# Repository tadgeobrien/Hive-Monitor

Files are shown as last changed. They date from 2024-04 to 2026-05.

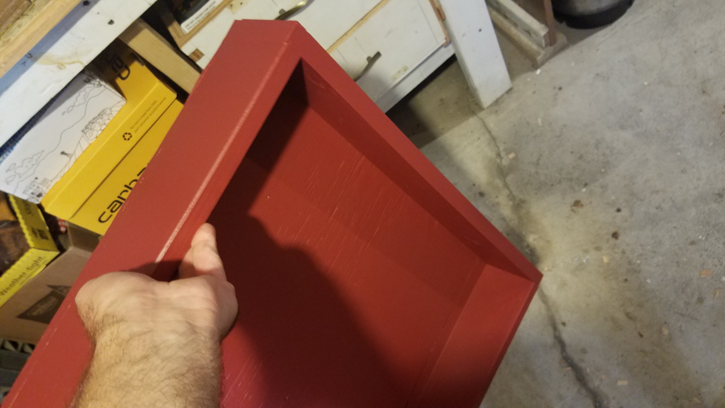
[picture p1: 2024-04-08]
ProgressPics/20220801_100242.jpg

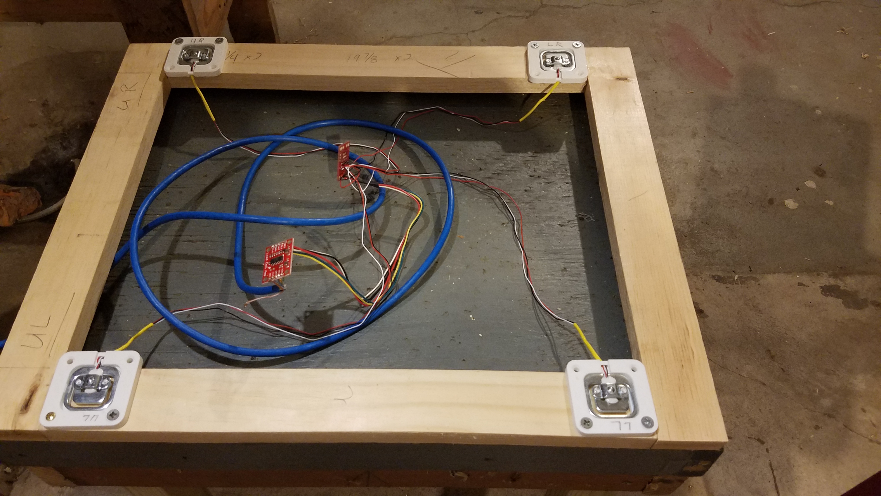
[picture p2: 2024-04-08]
ProgressPics/20220707_214736.jpg

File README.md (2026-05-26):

# Development Log

#20260525 

CURRENT WORKING FILE HiveMonitor-20260525-01/HiveMonitor-20260525-01.ino

I am going to redo this. I am going to focus on just getting things into openlog first. I am going to start with the temperatures and then add the scale.

- [X] Outside temperature working Serial Out. Need to verify inside OpenLog.
- [X] Inside Temp should be working now too.

Was messing with the zeroing and this is the number I was getting back. Not sure if it is correct. But Just using as a reference at this point.
Remove all weight from the loadcell
15:21:51.644 -> and press enter
15:21:51.644 -> 
15:22:13.270 -> Determine zero weight offset
15:22:14.995 -> OFFSET: 8388607
15:22:14.995 -> 
15:22:14.995 -> place a weight on the loadcell
15:22:14.995 -> enter the weight in (whole) grams and press enter
15:22:45.779 -> WEIGHT: 1134
15:22:47.438 -> SCALE:  0.000000
15:22:47.438 -> 
15:22:47.438 -> use scale.set_offset(8388607); and scale.set_scale(0.000000);
15:22:47.438 -> in the setup of your project

## 20250703 @ 18:02 - 
  TOBrien made a copy of the old hive monitor from 2024 and tried to get the weight to print. Currenlty not getting weight to print, but also appears that the one wire (external temp) is broken as I am seeing 
  -127 as a value. It was working before, but I have no idea what code I was actually running. I think I am going to make a text weight set of code and see if I can get that working with out anything else. 
  
  Currenlty working on the weight. Appears to be holding a decent "lbs" related to what I think I should get. 
  Next set of steps. 
  
- [X] I think I should get a hive body and mout it to the physical box that I have and apply wire the basic electronics. Teflon tap around humidity sensor and 1/8" wire mesh around the hole. 
- [X] Need an outdoor electronics box to put underneath to hold the scale components.
- [ ] Then I should look at how I am going to secure and waterproof the stuff that I have. Most likely silicoln over wires and connections. 
- [ ] Then start to look at how are you going to address the solar component of this. 
- [ ] Clear silicoln to cover any electronics that might be exposed (wiring mostly) 
- [ ] Define sample rate. I think that every 30 minutes would be sufficent. It would give you a sense of material coming in and going out I would think.

# Hive Montitor

NOTE--- I used the Sparkfun Qwiic shield which was originaly designed for the Uno. However the Uno Wifi Rev2 that I have has two pins that are different. 
        So to solve this the following has to be done. (https://forum.sparkfun.com/viewtopic.php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)
        
        The pins not going in all the way is normal, it's caused by the USB connector being higher than normal.
        We haven't tested the Qwiic Shield on the Uno WiFi V2 but it should work with this small change:
            Connect a jumper wire from A5 to SCL
            Connect a jumper wire from A4 to SDA

        The reason for the jumper wires is that the shield was made for the regular non WiFi Uno where the I2C pins are on A4 and A5 and the Uno WiFi V2 moves those pins over to the other side of the board. With the jumpers in place, the shield will work even though it doesn't sit flush with the Arduino. 

Of course now they have the Uno R4 Wifi which has a Qwiic connector built in GRRRR https://store-usa.arduino.cc/products/uno-r4-wifi .

## Winterizing
Not sure how the batteries would hold up in the winter. Would really need to look at this as I don't want to start a fire. 

## Goal

Create a simple set of sensors to monitor a beehive of mine. It will be solar powered and not connected to any network. 
The sensors that I will be using are as follows:
* Weight Measure
* Inside Temperature and Humidity Measure
* Outside Temperature Measure
* Leverage Meshtastic service to send a daily update via LoRa

## To Dos
- [ ] Should do something so I can zero the scale. Use the wifi control to do this?
- [ ] Do I need a way to update the current data on the webpage from the webpage without adding to the Openlog file?
- [ ] Implement battery power reading on webpage and openlog?
- [ ] Implement solar power 
- [ ] Implement way to download Data from web pagea
- [ ] Set up low power mode on anything that can do it. Ie WiFi.lowPowerMode() for the wifi.
- [X] Have RTC implemented on website TOBRIEN 20251229 I think that this is working right now.
- [X] Implement Weight measures (may leave with weight errors currently.) https://learn.sparkfun.com/tutorials/load-cell-amplifier-hx711-breakout-hookup-guide/all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 https://github.com/bogde/HX711/
- [X] Have Openlog recieving all current values of data
- [X] Have Openlog implemented and getting data
- [X] Have RTC working
- [X] Have Inside temp and humidity report on website
- [X] Have Inside humidity working
- [X] Have Inside temp working 
- [X] Have Outside temp appear on webpage.
- [X] Set up Onewire for outside temperature 
- [X] Set up an Webserver and wireless connection to the Arduino. 

## CSV Structure

CSV Structure should look like this. 
(24 entries per day and role log monthly would give at most 744 points of data.)
Could scale up if needed in the future.

Not sure if the date will go as I want, but I should try. Also not sure exactly if I would want it like
this or break it out Year,Month,Day,Hour,Minute,

DATE,TIME-24:00,% Humidity,InternalTemp(C),OutsideTemp(C),Weight(lbs)
20240420,00:20,24,31,1,95
20240420,01:20,24,31,1,95
20240420,02:20,24,31,1,95
20240420,03:20,24,31,1,95
20240420,04:20,24,31,1,95
20240420,05:20,24,31,1,95
20240420,06:20,24,31,1,95
20240420,07:20,24,31,1,95
20240420,08:20,24,31,1,95
20240420,09:20,24,31,1,95
20240420,10:20,24,31,1,95
20240420,11:20,24,31,1,95
20240420,12:20,24,31,1,95
20240420,13:20,24,31,1,95
20240420,14:20,24,31,1,95
20240420,15:20,24,31,1,95
20240420,16:20,24,31,1,95
20240420,17:20,24,31,1,95
20240420,18:20,24,31,1,95
20240420,19:20,24,31,1,95
20240420,20:20,24,31,1,95
20240420,21:20,24,31,1,95
20240420,22:20,24,31,1,95
20240420,23:20,24,31,1,95
  
### CSV Example 20250703  
07/03/2025,17:37:23,72.45,23.56,23.00,weigth
07/03/2025,17:37:43,72.44,23.55,23.00,weigth
07/03/2025,17:38:04,72.43,23.52,23.00,weigth
07/03/2025,17:38:25,72.41,23.52,23.00,weigth
07/03/2025,17:38:45,72.38,23.52,22.94,weigth
07/03/2025,17:39:06,72.36,23.52,23.00,weigth
07/03/2025,17:39:26,72.42,23.51,23.00,weigth
07/03/2025,17:39:47,72.45,23.51,23.00,weigth
07/03/2025,17:40:08,72.43,23.53,23.00,weigth

  */

# I2C addresses in Use
I think I need to verify all of these, but I don't think that this is why OpenLog isn't working. 
* RTC 0x32
* OpenLog 0x2A (42)

# Arduino Code

## Variables
* OutCel is for outside temperature in Celsius.
* OutFah is for the outside temp in Farenheit. May not even implement this to start.
* InCel is for the inside temperature coming from the humidity sensor in Celsius
* InFah is for the inside temperature coming from the humidity sensor in Farenheit. May not even implement to start.
* InHum is for the inside humidity. Not sure of the measurement.

## Functions
You should look at what your functions are actually returning here.

* void printWiFiStatus()
* void OutsideTemp()
* void InsideTemp()
* void InsideHumidity()

## Pinouts

# Hardware Notes

## Bill of Materials (BOM)
Maybe I should make this a table :)

* Arduino Uno Wifi R2
* [Real Time Clock Sparkfun BOB-16281](https://learn.sparkfun.com/tutorials/real-time-clock-module---rv-8803-qwiic-hookup-guide)
* [Humidity Sensor SparkFun SEN-16467](https://learn.sparkfun.com/tutorials/sparkfun-humidity-sensor-breakout---shtc3-qwiic-hookup-guide)
* Onewire Temperature sensor
* [Sparkfun Qwiix OpenLog](https://learn.sparkfun.com/tutorials/qwiic-openlog-hookup-guide)
* Sparkfun QWICC shield for Arduino
* Load Cells https://www.sparkfun.com/load-sensor-50kg-generic.html

### OLD BOM Stuff
* [Arduino Uno Wifi Rev 2](https://docs.arduino.cc/hardware/uno-wifi-rev2) Quantity 1
* [SparkFun Load Sensor Combinator](https://www.sparkfun.com/products/13878) Quantity 1
* [SparkFun Load Cell Amplifier - HX711](https://www.sparkfun.com/products/13879) Quantity 1
* [Load Sensor - 50kg (Generic)](https://www.sparkfun.com/products/10245) Quantity 4
* [Temperature Sensor - Waterproof (DS18B20)](https://www.sparkfun.com/products/11050) Quantity 1
* [SparkFun Air Quality Breakout - CCS811](https://www.sparkfun.com/products/14193) Quantity 1
* 4 - [Load Sensor](https://www.sparkfun.com/products/10245) Double check what weight I ordered.
* 1 - [SparkFun Load Sensor Combinator](https://www.sparkfun.com/products/13878) Also can have a DS18B20 wired in to measure temperature for variance. Maybe helpful for the graphing in winter. Not sure how to configure that part of it yet.
* 1 - [SparkFun Load Cell Amplifier - HX711](https://www.sparkfun.com/products/13879)
* Just another example https://pmc.ncbi.nlm.nih.gov/articles/PMC7248914/

# Load Cell Notes

Note: If you are hooking together four of the SparkFun Load Sensors using the Combinator board, you should position the four load sensors equidistant from each other, just like the bathroom scales shown in this tutorial.

## Load Cell Wiring
For load sensors, there isn't a set color coded standard. The hacked home scale can have different wire colors. Comparing the scale pictured above with the load sensor schematic, while the black wires matched, the red and white wires were swapped. Also, only two of the four sensors used a white wire for the 'center tap' of the load sensor, the other two used green. I connected the black wires to "-", the red to "+", and the white and green wires to "C".

To determine how to hook up your single strain gauge load cells to the combinator, measure the resistance with a multimeter between the three wires. You should find a larger resistance (close to double) between a pair. In our example, the resistance between red and black was 1.6 kΩ (i.e. 1600Ω), and the resistance between white/green and red was 800 Ω. Therefore, the center tap to the strain gauge is the white/green wire. The center tap or center pin of your strain gauge connects to the "C" pin on the combinator. The larger resistance wires (red and black in this example) connect to the "+" and "-" pins on the combinator.

## Load Cell SUDO code

Load cell comes online.
Load cell has the option to TARE via the web UI
  If tare is initiated it updates this information and then reports that it was successful.
  If no tare is initiated it starts taking reading or waits for tare initiation.

## Tutorials
* [Load cell](https://learn.sparkfun.com/tutorials/load-cell-amplifier-hx711-breakout-hookup-guide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)

# OLD INFO BELOW Pre 20240410

# Hive-Monitor
Creating a simple bee hive monitoring system for a public garden space. Likely using Arduino and maybe a Rasberry Pi. (Basically Modelling after this [Makezine Article](https://makezine.com/projects/bees-sensors-monitor-hive-health). [The data I would like to look like this](http://everettsprojects.com/2012/12/31/arduino-super-graphing-data-logger/). I would like it if I could set it up as a hotspot that people could click on the data to view it. Ie connect to 490hive wireless and be directed to www.home.arpa where you can choose what to see ie. Hive Weight Hive Temperature Hive Humidity for last N days. 

Alternate ways to [view data..](https://www.electronicsforu.com/electronics-projects/graphical-data-display-arduino-html5).

# Goal

Do you look at something like this for easy logging an implementation? [SparkFun OpenLog Artemis (without IMU)](https://www.sparkfun.com/products/19426). You then become a bit locked into a specific type of thing. Also would need to change to a board similar to the  [SparkFun Thing Plus - ESP32 WROOM (Micro-B)](https://www.sparkfun.com/products/15663)

# To Do
- [ ] Build a power profile and how to charge the battery. 
- [ ] Decide on whether to leverage QWICC from Sparkfun.
- [ ] Decide on where to put enclosure. I think that mounting it to the hive base or in the quilt box would be the best option. If it is in the quilt box then the length for the load cells will be the longest. Likely look at using an rj45 to do that connection and running the wires back up. Should be able to do the load cell on a single rj45 cable. 
- [ ] Decide on wiring paths (think about how you will add/remove supers and lengths of cabling)

# BOM
I think I need to adjust this. Thinking more along the lines of QWIIC since it might be easier, even though it won't neccesarily be cheaper. 
(SEE FILE)

## OLD BOM Stuff
* [Arduino Uno Wifi Rev 2](https://docs.arduino.cc/hardware/uno-wifi-rev2) Quantity 1
* [SparkFun Load Sensor Combinator](https://www.sparkfun.com/products/13878) Quantity 1
* [SparkFun Load Cell Amplifier - HX711](https://www.sparkfun.com/products/13879) Quantity 1
* [Load Sensor - 50kg (Generic)](https://www.sparkfun.com/products/10245) Quantity 4
* [Temperature Sensor - Waterproof (DS18B20)](https://www.sparkfun.com/products/11050) Quantity 1
* [SparkFun Air Quality Breakout - CCS811](https://www.sparkfun.com/products/14193) Quantity 1

# Physical Design Docs
Thinking this would be any CAD files or drawings. 

# General Design Questions per Sensor or piece.
Thinking if you use RJ45 as connectors you'd want to look at [waterproof enclosures](https://www.amazon.com/Waterproof-Connector-Shielded-Ethernet-Tedgetal/dp/B095JZSGYG). [waterproof enclosure](https://www.homedepot.com/p/Revo-RJ45-Female-to-Female-Waterproof-IP-67-Outdoor-Coupler-ONC-1/310016205)

## Battery and Solar Requirements
* [LiFePO4 Battery](https://www.amazon.com/LiFePO4-Battery-Miady-Rechargeable-Maintenance-Free/dp/B089VXSBC6/?th=1) similar to this? 
* [Crowd Supply makerPower Solar](https://www.sparkfun.com/products/16352) seems like the right fit. Only question is how would it be designed for a lead battery vs. the lithium iron? 
* [SparkFun Sunny Buddy - MPPT Solar Charger](https://www.sparkfun.com/products/12885) Would this work at all? Designed for a single cell LiPo battery. 
* May need to have a lenght of cable for powering things. Not sure how I would do this. Most likely send the power from the panel to the inverter close to the actual sensors. (4mm pv cable for solar power. It is DC) I think that the distance would be about 20 feet or so for this application. Othe concerns would be grounding.

* [Open Source Solar System](https://opensource.com/article/22/12/open-source-solar-power-home) Just some notes on a solar system.

### Solar Implementation
* [ Sunny Buddy Solar Charger V13 Hookup Guide](https://learn.sparkfun.com/tutorials/sunny-buddy-solar-charger-v13-hookup-guide-) This is what I have purchased.
* I would like a way to read the batter power from this if possible.
* Looks like there is some tuning needed for this prior to use.
* [Sunny Buddy product page](https://www.sparkfun.com/sparkfun-sunny-buddy-mppt-solar-charger.html)

### Battery Implementatoin
* Should be able to get everything set up so that it will run on batteries and the solar is the charging piece.

## Load Cells Requirements
In the one from Sparkfun he hacks a premade scale. I could go to a second hand store or buy one from amazon. I already have 4 load cells. So I could try to build a simple one with a square piece of plywood and some pressure treated 2x4s. I would build the square and put the cells in the corners then mount this inside of the hive stand. The accuracy of this is the biggest question. 

## Temperature and Humidity Requirements
* Needs to be able to measure both of these and I am thinking of placing them on the top of the hive. Would like to understand how best to build the enclosure to get decent readings. 

# Libraries Used

* [HXHX711 Arduino Library](https://github.com/bogde/HX711)
* [OneWire](https://www.arduino.cc/reference/en/libraries/onewire/)

# References Used
Here is a list of things like Youtube videos that I used for reference.

[Arduino Scale with HX711 and 50kg Bathroom Scale Load Cells | Step by Step Guide.](https://www.youtube.com/watch?v=LIuf2egMioA)

[Load Cell Amplifier HX711 Breakout Hookup Guide ](https://learn.sparkfun.com/tutorials/load-cell-amplifier-hx711-breakout-hookup-guide)

====

# Older Stuff from initial hive spy project.

# Maybe Helpful
* https://github.com/fubar2/piloadcell

# Wireless AP part
I want to make it so that basically it broadcasts an SSID that you can connect to and see what the Hive Spy has been collecting.

https://raspap.com/

or HospAPD  (This is likely going to be around longer I would think.)
https://learn.adafruit.com/setting-up-a-raspberry-pi-as-a-wifi-access-point/compiling-hostapd?view=all
https://hawksites.newpaltz.edu/myerse/2018/06/08/hostapd-on-raspberry-pi/
https://www.instructables.com/Raspberry-Pi-Wifi-Hotspot/

# Links for File Download

https://forum.arduino.cc/t/file-download-with-arduino-web-server/160140
https://forum.arduino.cc/t/download-files-on-the-wifiwebserver/692379

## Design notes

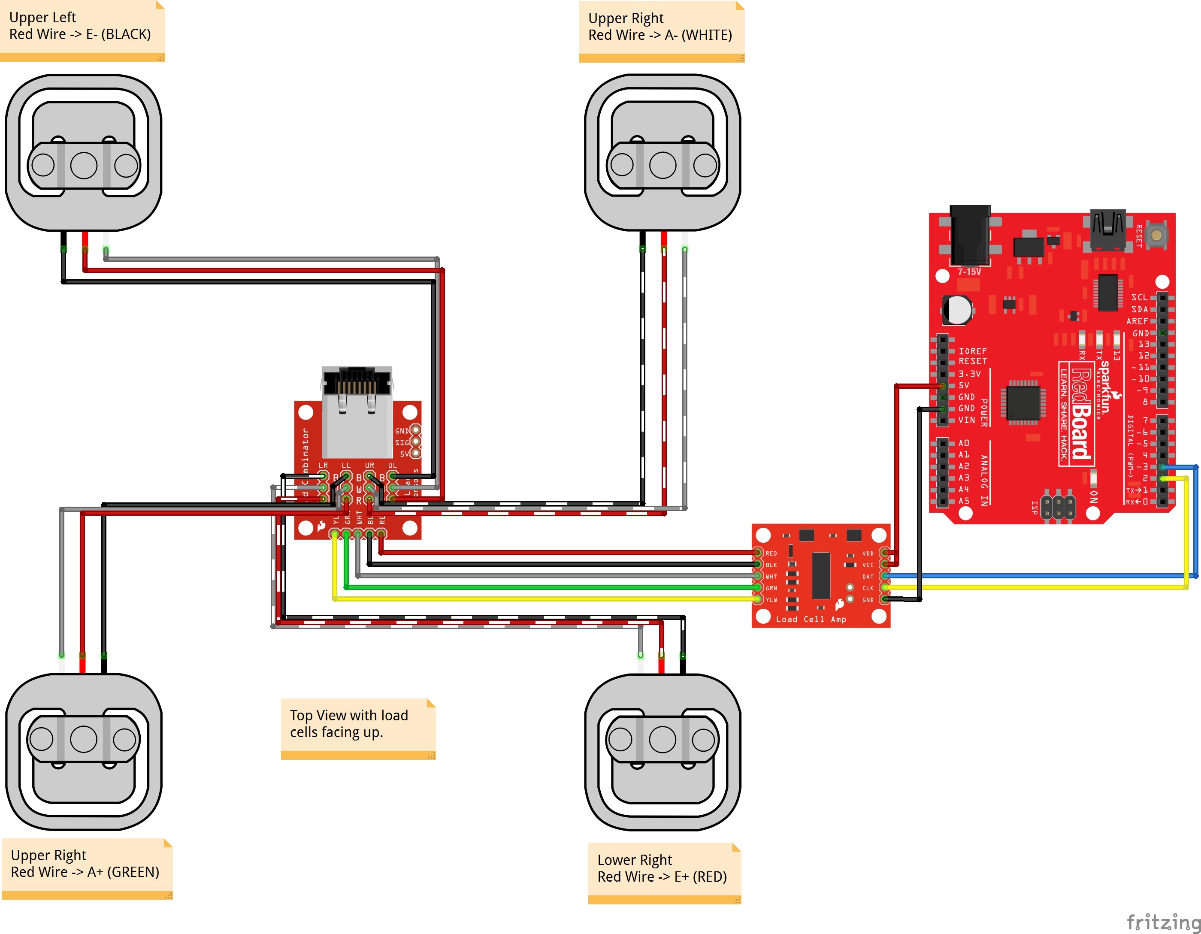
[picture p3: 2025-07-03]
SparkFun_Wheatstone_Bridge_Load_Sensor_HX711_bb_Fritzing.jpg

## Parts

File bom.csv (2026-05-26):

quantity | common name | URL
1 | SparkFun Humidity Sensor Breakout - SHTC3 (Qwiic) | https://www.sparkfun.com/sparkfun-humidity-sensor-breakout-shtc3-qwiic.html
1 | Temperature Sensor - Waterproof (DS18B20) | https://www.sparkfun.com/temperature-sensor-waterproof-ds18b20.html
1 | SparkFun Sunny Buddy - MPPT Solar Charger | https://www.sparkfun.com/sparkfun-sunny-buddy-mppt-solar-charger.html
1 | Lithium Ion Battery - 6Ah | https://www.sparkfun.com/products/13856
1 | Solar Panel - 3.5W | https://www.sparkfun.com/products/13782
1 | Arduino Wifi Rev 2 | https://docs.arduino.cc/hardware/uno-wifi-rev2/
1 | SparkFun Humidity Sensor Breakout - SHTC3 (Qwiic) | https://www.sparkfun.com/sparkfun-humidity-sensor-breakout-shtc3-qwiic.html
1 | SparkFun Real Time Clock Module - RV-1805 (Qwiic) | https://www.sparkfun.com/sparkfun-real-time-clock-module-rv-1805-qwiic.html
1 | SparkFun Qwiic OpenLog | https://www.sparkfun.com/sparkfun-qwiic-openlog.html
1 | SparkFun Qwiic Shield for Arduino | https://www.sparkfun.com/sparkfun-qwiic-shield-for-arduino.html
1 | SparkFun Load Cell Amplifier - HX711 | https://www.sparkfun.com/sparkfun-load-cell-amplifier-hx711.html
1 | SparkFun Load Sensor Combinator | https://www.sparkfun.com/sparkfun-load-sensor-combinator.html

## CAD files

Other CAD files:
CAD-Design.FCStd

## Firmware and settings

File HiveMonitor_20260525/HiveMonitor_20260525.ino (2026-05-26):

//T OBRIEN 20240409
// Taken from https://docs.arduino.cc/tutorials/uno-wifi-rev2/uno-wifi-r2-web-server-ap-mode/
//
// So now can I modify this so that I am passing sensor data to the page? 
//
//  - Onewire is for external temperature of the hive. Still need to figure out
//    where I would want to put the sensor itself.
//  
//  - QWICC should probaly document the i2c addresses.
//
//  RTC Notes - run 24 hour clock run MM/DD/YYYY I think would make the most sense unless something else makes the data processing different.
//      Or you can use  timestamp in ISO 8601 format (yyyy-mm-ddThh:mm:ss).
//
//  OpenLog Notes - Do you simply create a file for every day of a month and a folder for the month. Then a folder for they year? 
//        Or do you simply create a file to X MB size and then have it time stamp when it creates the file? 
//        I really think the thing here is how do you want to download the data? If you download it periodly with your phone 
//        then you have to think about he file manipulation. If you pull the SD card who cares. (I will pull the SD at the end of the season I think regrdless.
//  
//        Perhaps I do a file write a week and download a weeks worth of data? That would make a lot of sense. What is my weekly start and end date? 


//// Libraries I am using
#include <WiFiNINA.h>           //Wifi Library
#include <OneWire.h>            // Takes in the data.
#include <DallasTemperature.h>  //Does calculations and conversion.
#include <SparkFun_RV8803.h>    //Real Time Clock 
#include <SparkFun_SHTC3.h>     //Using for inside Humidity and Temp
#include <SparkFun_Qwiic_OpenLog_Arduino_Library.h>
#include "HX711.h"

//Scale HX711 circuit wiring
uint8_t dataPin = 2;
uint8_t clockPin = 3;

//Adding Classes
RV8803 rtc;       // Declare an instance of the RV8803 class
SHTC3 mySHTC3;    // Declare an instance of the SHTC3 class
OpenLog myLog;    // Declare an instance of the OpenLog class
HX711 scale;      // Declare an instance of HX711 scale class

//Wireless network details.
char ssid[] ="HiveMind";
char pass[] = "Password";  // Can I keep this open? What are the risks?
int keyIndex = 0; //Only for WEP

// One wire setup.
#define ONE_WIRE_BUS 5  //READ IS ON PIN 5
OneWire oneWire(ONE_WIRE_BUS);
DallasTemperature sensors(&oneWire);

float OutCel=0; // Outside Celcius tobrien 20240410. May simply implement this instead of conversions.
float OutFah=0; // Outside Fahrenheit

// Setting up for Humidity sensor.
float InCel=0;  // Inside Celcius temp
float InFah=0;  // Inside Farenheit May not use.
float InHum=0;  // Inside Humidity 

//LED Testing tobrien 20240410 keep or remove?
int led = LED_BUILTIN;
int status = WL_IDLE_STATUS;  // TOBRIEN 20260118. I think this is actually related to the wifi not the LED.
//Defines server port.
WiFiServer server(80);

void setup() {
  // put your setup code here, to run once:

  pinMode(LED_BUILTIN, OUTPUT);   // TOBRIEN 20260118. Think I would like to add an external LED. Not sure if I have to do anything special other than wire it up.

  Wire.begin();     // This is to start the i2c bus I believe
  mySHTC3.begin();  // This calls the SHTC3 sensor to start
  rtc.begin();      // This calls the RTC to start
  rtc.set24Hour();  // This sets RTC to 24 hour clock
  scale.begin(dataPin, clockPin); // Setting up for the Scale. 
  scale.set_scale(127.15);       //  TODO you need to calibrate this yourself.  
  scale.tare();

  
  Serial.begin(9600);
  while (!Serial){
    ; //wait for serial port to connect. Needed for Native USB  Port only -- Huh?
    }

    Serial.println("Access Point Web Server");

    pinMode(led, OUTPUT); //Set pin Mode

    // Check for WiFi Module
    if (WiFi.status() == WL_NO_MODULE){
      Serial.println("Communication with Wifi Module failed!");
      //Don't continue
      while(true);
      }

      String fv = WiFi.firmwareVersion();
      if (fv < WIFI_FIRMWARE_LATEST_VERSION){
        Serial.println("Please upgrade the firmware");
        }

        //print the network name (SSID);
        Serial.print("Creating access point named: ");
        Serial.println(ssid);

        // Create open network. Change this line if creating a WEP network.
        status = WiFi.beginAP(ssid, pass);
        if (status != WL_AP_LISTENING){
          Serial.println("Creating access point failed");
          //Don't continue
          while(true);
          }

          //Wait 10 seconds for connection
          delay(10000);

          // start web server on port 80.
          server.begin();

          //you are connected now print the status
          printWiFiStatus();

  //  load cell factor 5 KG
//  scale.set_scale(8388607);       // TOBRIEN 20260525 Used the value for earlier scale calibration. Think that this might not be correct.
  //  reset the scale to zero = 0
//  scale.tare(20);  //TOBrien 20260525 need to watch this may also need to adjust.

}

void loop() {
  // put your main code here, to run repeatedly:
  
 
  ////////////////////////////////////////////////////
  //  This is the Wifi AP
  ////////////////////////////////////////////////////
  // compare the previous status to the current status
  if (status != WiFi.status()){
    //it had changed update the variable
    status = WiFi.status();

    if (status == WL_AP_CONNECTED){
      //a device has connected to the AP
      Serial.println("Device connected to AP");
      }else{
      // a device had disconnected from the AP
      Serial.println("Device disconnected from the AP");
        }
    }

    WiFiClient client = server.available(); // listen for incoming clients

    if (client){                      // if you get a client,
      Serial.println("new client");  // print a message out the serial port
      String currentLine = "";        // make a String to hold incoming data from the client
      while (client.connected()){     // loop while the client's connected
        if (client.available()){      // if there's bytes to read from the client,
          char c = client.read();     //read a byte then
          Serial.write(c);            // print it out the serial monitor
          if (c == '\n'){             // if the byte is a newline character
            // if the current line is blank, you got two newline characters in a row.
            // that's the end of the client HTTP request, so send a response:
            if (currentLine.length()==0){
               // HTTP headers always start with a response code (e.g. HTTP/1.1 200 OK)
              // and a content-type so the client knows what's coming, then a blank line:
              client.println("HTTP/1.1 200 OK");
              client.println("Content-type:text/html");
              client.println("");
            
            // the content of the HTTP response follows the header:
            // TOBRIEN Eventually get rid of this.
              client.print("Click <a href=\"/H\">here</a> turn the LED on<br>");
              client.print("Click <a href=\"/H\">here</a> turn the LED off<br>");

              
              //TOBrien implement the printing of the Data to the web interface
              client.println(String(rtc.stringDateUSA()));
              client.println(String(rtc.stringTime()));
              client.print("<br>Outside Temperature = ");
              client.println(OutCel);
              client.print("<br>Inside Relative Humidty = ");
              client.print(mySHTC3.toPercent());
              client.println("% <br>");
              client.print("Inside Temperature = ");
              client.print(mySHTC3.toDegF());
              client.println(" deg F"); //Need to change to C
              client.println("<br>Weight");
              client.println(scale.read());
//              client.println(reading());

              //HTTP response ends with a blank line.
              client.println();
              //break out the while loop
              break;
              }else{ 
                // if you got a newline then clear current line
                currentLine = "";
                }
            
            }else if (c != '\r'){
                                      // if you got anything else but a carriage return character,
              currentLine += c;      // add it to the end of the currentLine
              }

              //Check to see if client requests was Get /H or Get /L
              if (currentLine.endsWith("GET /H")){
                digitalWrite(led, HIGH);
              }
              if (currentLine.endsWith("GET /L")){
                digitalWrite(led, LOW);
                }
           }
        }
        // close the connection
        client.stop();
        Serial.println("Client disconnected");
      }

      //Date and Time
      myTime();
      
      //Outside temp in C
      //OutsideTemp();  // This should be my function to check outside temp.
      sensors.requestTemperatures();
      OutCel=sensors.getTempCByIndex(0); //Get Outside C from Onewire.

      //Inside hive monitoring
      SHTC3_Status_TypeDef result = mySHTC3.update(); //Update the sensor
      //InsideHive();


      // Lets write some data to OpenLog Below is an example
        /*    DATE,TIME-24:00,% Humidity,InternalTemp(C),OutsideTemp(C),Weight(lbs)
            20240420,00:20,24,31,1,95
            20240420,01:20,24,31,1,95
            20240420,02:20,24,31,1,95
            20240420,03:20,24,31,1,95
      */
      myLog.begin();
      // Printing this string to the OpenLog
      //myLog.println(String(rtc.stringDateUSA())+","+String(rtc.stringTime())+","+String(mySHTC3.toPercent())+","+String(mySHTC3.toDegC())+","+String(OutCel)+",weight");
      myLog.println(String(rtc.stringDateUSA())+","+String(rtc.stringTime())+","+String(mySHTC3.toPercent())+","+String(mySHTC3.toDegC())+","+String(OutCel)+","+String(scale.read()));// FOR ADDING WEIGHT WHEN READY

      // Printing the same string to Serial output so I can verify it      
      //Serial.println(String(rtc.stringDateUSA())+","+String(rtc.stringTime())+","+String(mySHTC3.toPercent())+","+String(mySHTC3.toDegC())+","+String(OutCel)+",weight");
      Serial.println(String(rtc.stringDateUSA())+","+String(rtc.stringTime())+","+String(mySHTC3.toPercent())+","+String(mySHTC3.toDegC())+","+String(OutCel)+","+String(scale.read()));// FOR ADDING WEIGHT WHEN READY

      //
      // Just leaving this here since I am getting a declareation error. 
      //Serial.println(String(rtc.stringDateUSA())+","+String(rtc.stringTime())+","+String(mySHTC3.toPercent())+","+String(mySHTC3.toDegC())+","+String(OutCel)+","+HiveWeight);  
      //
      myLog.syncFile();
}

void printWiFiStatus(){
  //print the ssid of the net you are connected to
  Serial.print("SSID: ");
  Serial.println(WiFi.SSID());
  // print your wifi shields IP Address
  IPAddress ip =  WiFi.localIP();
  Serial.print("IP Address: ");
  Serial.println(ip);
  }
 

void myTime(){
// TOBrien 20260118 Should really return a value on this and pass it differently.

//Updating the time here
//
// Trying to decide how I want to do this. I can either just send the entire date from RTC which would be the easy way
// I could also put it in the format that I want Year-Month-Day-HH:MM:SS and either send that as seperate fields 
// in the CSV file or at least order it based on the date and then time 

// I may start it out the easy way and then look at the data and see what I like, dislike 

  rtc.updateTime();
  if (rtc.updateTime() == true) //Updates the time variables from RTC
  {
      String logDate = rtc.stringDateUSA();
      String logTime = rtc.stringTime();

  }

  // 3 Seconds Testing
  //delay(3000);
  delay(10000);
  // 3 Minutes First field testing
  //delay(180000);
  // One hour
  //delay(3600000);
}

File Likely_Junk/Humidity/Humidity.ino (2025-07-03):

/*
  Take humidity and temperature readings with the SHTC3 using I2C
  By: Owen Lyke
  SparkFun Electronics
  Date: August 24 2018
  License: This code is public domain but you buy me a beer if you use this and we meet someday (Beerware license).
  Example1_BasicReadings
  To connect the sensor to an Arduino:
  This library supports the sensor using the I2C protocol
  On Qwiic enabled boards simply connnect the sensor with a Qwiic cable and it is set to go
  On non-qwiic boards you will need to connect 4 wires between the sensor and the host board
  (Arduino pin) = (Display pin)
  SCL = SCL on display carrier
  SDA = SDA
  GND = GND
  3.3V = 3.3V
*/

#include "SparkFun_SHTC3.h" // Click here to get the library: http://librarymanager/All#SparkFun_SHTC3

SHTC3 mySHTC3;              // Declare an instance of the SHTC3 class

void setup() {

  Serial.begin(9600);                                  // Begin Serial 
//  while(Serial == false){};                                   // Wait for the serial connection to start up
  Serial.println("SHTC3 Example 1 - Basic Readings");    // Title
  Wire.begin();
  Serial.print("Beginning sensor. Result = ");           // Most SHTC3 functions return a variable of the type "SHTC3_Status_TypeDef" to indicate the status of their execution 
  errorDecoder(mySHTC3.begin());                              // To start the sensor you must call "begin()", the default settings use Wire (default Arduino I2C port)
  Serial.println();
  Serial.println("\n\n");
  Serial.println("Waiting for 5 seconds so you can read this info ^^^");

  delay(5000);                                                // Give time to read the welcome message and device ID. 
}

void loop() {
  SHTC3_Status_TypeDef result = mySHTC3.update();             // Call "update()" to command a measurement, wait for measurement to complete, and update the RH and T members of the object
  printInfo();                                                // This function is used to print a nice little line of info to the serial port
  delay(190);                                                 // Delay for the data rate you want - note that measurements take ~10 ms so the fastest data rate is 100 Hz (when no delay is used)
}



///////////////////////
// Utility Functions //
///////////////////////
void printInfo()
{
  if(mySHTC3.lastStatus == SHTC3_Status_Nominal)              // You can also assess the status of the last command by checking the ".lastStatus" member of the object
  {
    Serial.print("RH = "); 
    Serial.print(mySHTC3.toPercent());                        // "toPercent" returns the percent humidity as a floating point number
    Serial.print("%, T = "); 
    Serial.print(mySHTC3.toDegF());                           // "toDegF" and "toDegC" return the temperature as a flaoting point number in deg F and deg C respectively 
    Serial.println(" deg F"); 
  }
  else
  {
    Serial.print("Update failed, error: "); 
    errorDecoder(mySHTC3.lastStatus);
    Serial.println();
  }
}

void errorDecoder(SHTC3_Status_TypeDef message)                             // The errorDecoder function prints "SHTC3_Status_TypeDef" resultsin a human-friendly way
{
  switch(message)
  {
    case SHTC3_Status_Nominal : Serial.print("Nominal"); break;
    case SHTC3_Status_Error : Serial.print("Error"); break;
    case SHTC3_Status_CRC_Fail : Serial.print("CRC Fail"); break;
    default : Serial.print("Unknown return code"); break;
  }
}

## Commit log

2022-06-13 Update README.md
    Just creating a basic bill of materials of the things that I have and what I might be able to use.
2022-06-13 Update README.md
    Just updating the stuff around solar charging.
2022-06-13 Update README.md
    Updating related to RJ45 connectors.
2022-06-13 Update README.md
    Updating BOM and thinking about implementation.
2022-06-13 Create bom.csv
    Thinking that this makes a better BOM.
    [bom.csv]
2022-06-13 Update README.md
    Adjusting BOM.
2022-06-13 Update bom.csv
    Updated some links.
    [bom.csv]
2022-06-13 Update bom.csv
    Updating the needs for this.
    [bom.csv]
2022-06-28 Just adding something for storing data.
    [bom.csv]
2022-07-04 Just updating the git ignore and adding the HX711 calibration file.
2022-07-04 Thinking that this would be a good way to learn FreeCAD.
    [CAD-Design.FCStd]
2022-07-28 Just working on the temperature code for the system.
2024-04-10 This is currently working as the AP.
2024-04-10 Just implemented Onewire writing to serial. Need to upload and test, didn't have a resistor.
2024-04-11 At some point I have to build this within the Arduino I think so might as well start a rough idea now.
2024-04-11 This is the latest itteration of this. I don't love how Arduino always makes the seperate folders. Oh well.
2024-04-12 Implemented outside temperature so I have the one wire working and appearing on the WebUI.
2024-04-13 Just used Sparkfun for this BOM. The first two columns let me add to a wish list...
    [SparkfunWishList.csv]
2024-04-23 Have serial print of onewire and starting to put in the SHTC3 detail.
2024-04-24 Have it printing the date in serial. Adding Time next.
2024-04-24 Printing time stamp and time as I want at this point.
2024-04-28 Have it printing the time at this point. Going to clean up some of the serial prints and see if I can maintain what I have.
2024-04-28 Have the logs printing to Serial like I want. Next moving it to the log file.
2024-04-28 Just trying to update the documents related to the sensors I bought.
2024-04-28 Trying to extend the sample rate, but I think it is conflicting with the AP set up. Maybe I can make a function for the entire sampling piece?
2024-04-28 I think I am ready to implement the next piece which is power, then I will tackle weight I think.
2025-07-03 Just added everything at this point. Biggest add is the Scale testing. That is what I want to work on now.
    [Hive_Monitor.fzz]
2025-07-04 I think I have this working with the weight. The Outside temp is still broken but I think it is hardware right now.
    [LoadCell_Testing.ino]
2025-12-27 Arduino requires a folder.
2025-12-30 Just thinking about sample rates for data. 30 minutes should be fine.
2026-01-19 Just trying to mess around as I have an Uno with a Wired Ethernet shield.
2026-05-25 Just updating what prints on the web page.
2026-05-25 Just a test file as I can't seem to read it currently.
2026-05-25 Just trying to fix all of my mistakes....
    [HiveMonitor_20260525.ino]
2026-05-25 Cleaning up a few things. Trying to correct the Outside temperature.
    [HiveMonitor_20260525.ino]
2026-05-26 Trying to update this so It is more relevant.
    [bom.csv]
2026-05-26 Just redoing all the code. Starting with getting things working on serial and open log, then I will add the wireless.
2026-05-26 I forgot to add sensor.begin to the setup.
2026-05-26 Just adding the Wire.begin for Inside hive temp.
2026-05-26 Just updating some notes related to Wire.begin and spacing in the print statements.
